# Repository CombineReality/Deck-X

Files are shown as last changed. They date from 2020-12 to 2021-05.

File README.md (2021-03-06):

# Deck X
CombineReality's open-source AR headset based on Leap Motion's Project North Star.

 

We've created a new repo because our fork had gotten a little untidy and we weren't yet ready to make pull requests.

Many of the parts in this repo are either taken directly from Leap Motion's original mechanical design. The optics brackets are derivatives of Florian Maurer's <a href="https://github.com/leapmotion/ProjectNorthStar/tree/master/Mechanical/Development">version 3.2 development work.</a>

Calibration Stand folder & files are copied from the <a href="https://github.com/leapmotion/ProjectNorthStar">Project North Star repo</a>.

Assembly guide for Deck X with threaded inserts: https://project-north-star.gitbook.io/project-north-star/mechanical/combine-reality-deck-x/deck-x-assembly-guide (Assembly guide for Deck X without threaded inserts is coming soon!) If you have any questions about how things fit together, please check the STEP files and ask for help on the Discord server. We're here for you!

The original software setup and calibration instructions for Project North Star can be found here: https://project-north-star.gitbook.io/project-north-star/

You should also consult with the community on Discord to find out about the current state of North Star software development. There's a lot going on, and documentation updates are in the works.

<br>

## Resources
* Project North Star <a href="https://discord.gg/fV8qfWm">Discord</a>
* Our <a href="https://combinereality.com">website</a>
* Deck X <a href="https://project-north-star.gitbook.io/project-north-star/mechanical/combine-reality-deck-x/deck-x-assembly-guide">Assembly Guide</a>
* <a href="https://blog.leapmotion.com/northstar/">Leap Motion Blog</a>

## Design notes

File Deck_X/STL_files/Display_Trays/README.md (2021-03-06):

There are six total variations of the display trays; three each in versions either without heat-set threaded inserts. The three versions in each of these folders each gives the headset a different optical focal depth at the center of the combiners.

The 25cm trays are best-suited for software where the bulk of the visual content will be within arm's reach. These trays produce the brightest images and the widest field of view, but more distant objects suffer from a pronounced vergence / accomodation conflict that makes them seem a bit cartoonish.

The 75cm trays are best-suited for software where most of the visual content will be beyond arm's reach, or even at a distance of many meters. This optical arrangement loses several degrees of FoV on either side, and also results in noticeably a dimmer image. But the vergence / accomodation conflict for distant objects is rendered a non-issue.

The 50cm trays are a linear interpolation between the 25cm and 75cm arrangements, and were not part of Leap Motion's initial set of options. They do, however seem to sit in a sweet spot where they fill all of the field of view for most wearers of the headset, produce an acceptably bright image (bright white content is still very close to opaque when seen in an artificially lit room), and most importantly don't result in experience-breaking vergence / accomodation conflict for content at any distance for most users.

At Combine Reality, we're currently building all of our sample and evaluation headsets with the 50cm trays without inserts, but some people still have a preference for one of the others, and this project is all about flexibility.

(See the README in ../Optics_Bracket_Assembly/Optics_Bracket_Variants_(Main_Body) for an explanation of why you might or might not want to use the heat-set inserts.)

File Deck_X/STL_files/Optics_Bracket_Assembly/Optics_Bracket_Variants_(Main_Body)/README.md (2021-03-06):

The two directories here contain two versions of the optics bracket each. You only need one of these four optics brackets for your headset build.

In one directory there are brackets that use heat-set threaded inserts that need to be installed into the brackets using a soldering iron or other appropriately heated appropriate tool. The inserts prolong the life of your headset parts if you're going to frequently remove the lid to change the arrangement of sensors, or if you plan on swapping out display trays to change the optical focal depth of the headset. In the other you will find brackets that do not require these inserts.

Each directory contains a bracket for use with the classic Leap Motion controller, and another for the Rigel sensor, now renamed the Ultraleap Stereo IR 170 Camera Module.

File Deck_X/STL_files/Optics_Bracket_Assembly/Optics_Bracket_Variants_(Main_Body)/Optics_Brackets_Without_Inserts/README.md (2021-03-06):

This version of the Deck-X Project North Star headset does away with the threaded inserts found in other versions of the headset. The rationale for this is that while the inserts do reduce wear on the parts after repeated assembly and disassembly, not all North Star builders have a soldering iron on hand. Also, counterintuitively, the inserts can make parts fit together less precisely, as builders may install the inserts themselves with differing degrees of precision.

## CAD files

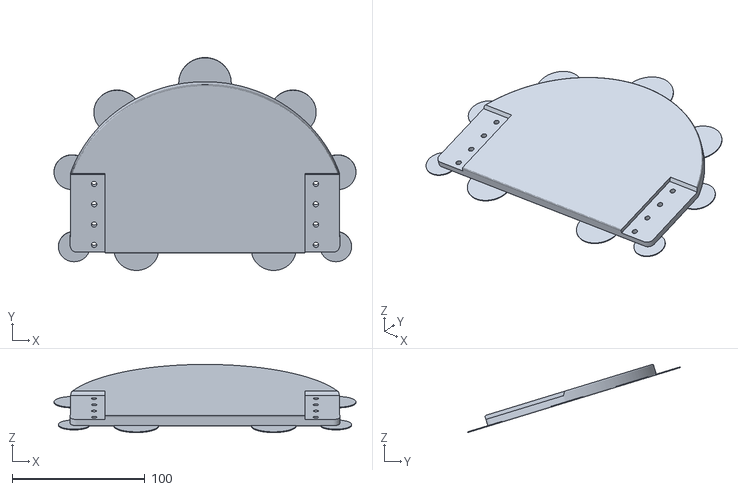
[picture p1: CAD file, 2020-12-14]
Calibration_Stand/#310-000 FDM OPTIMIZED.stl
227.5 x 160.4 x 51.4

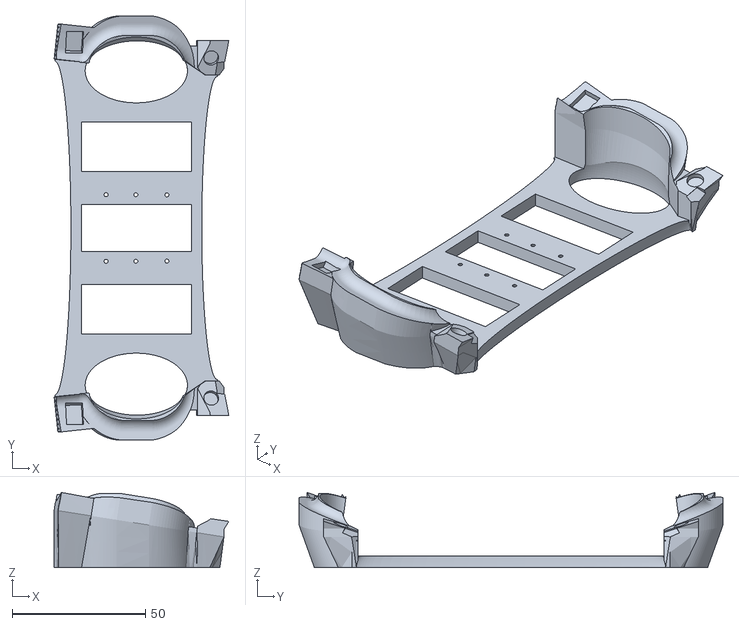
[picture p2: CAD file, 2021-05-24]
Deck_X/STL_files/Calibration_Accessories/DX_T261_Hybrid_Calibrator.stl
65.5 x 158.9 x 28.1

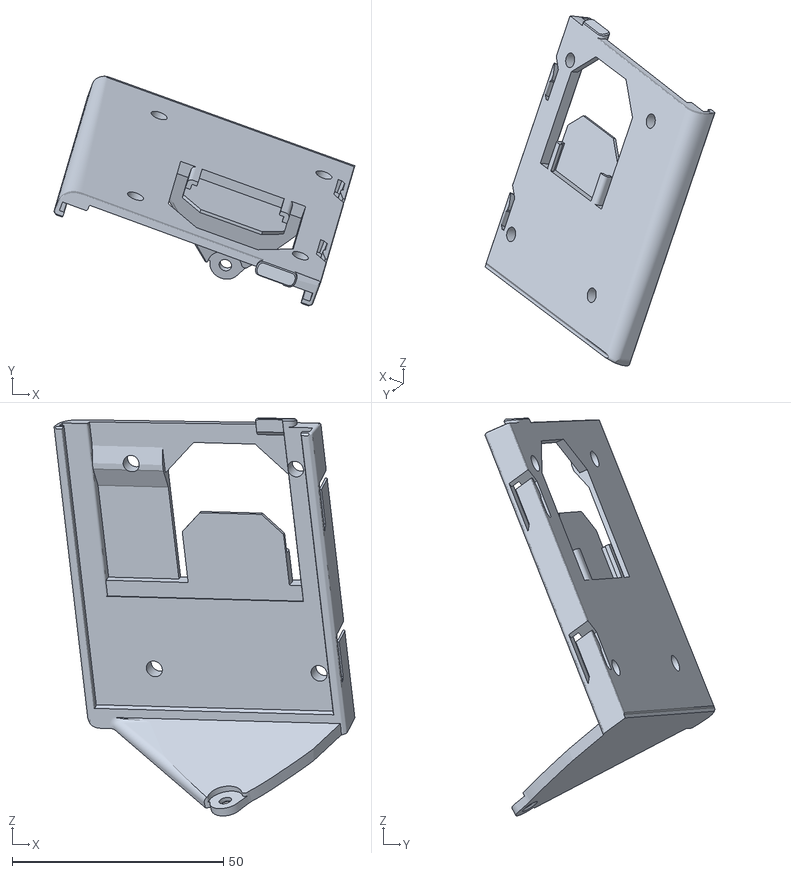
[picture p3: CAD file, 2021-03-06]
Deck_X/STL_files/Display_Trays/with_inserts/dx_tray_75_l_0105.stl
71.2 x 54.4 x 94.2

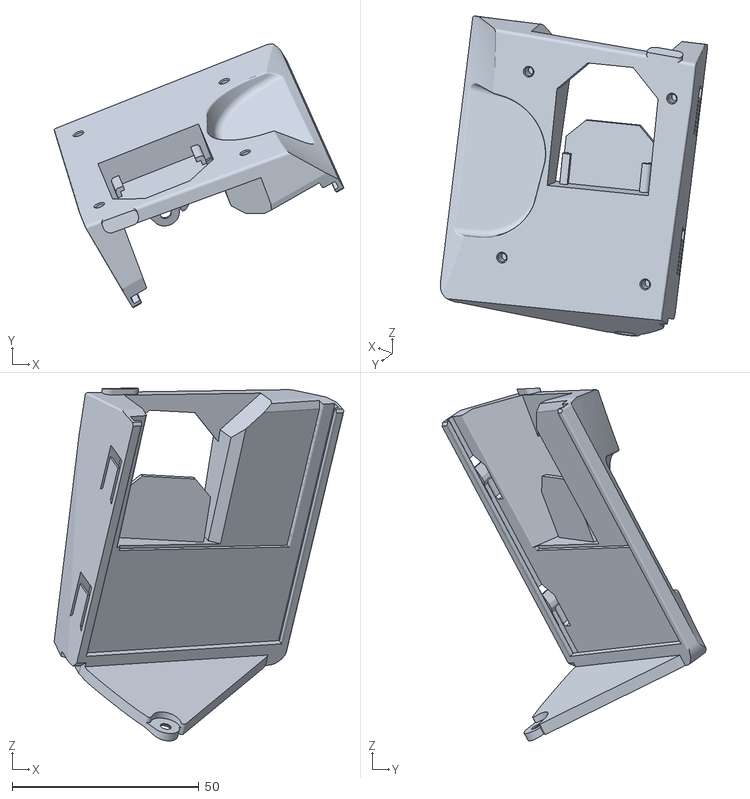
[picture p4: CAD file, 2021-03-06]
Deck_X/STL_files/Display_Trays/without_inserts/dx_tray_25_r_0105.stl
77.6 x 70.6 x 94.5

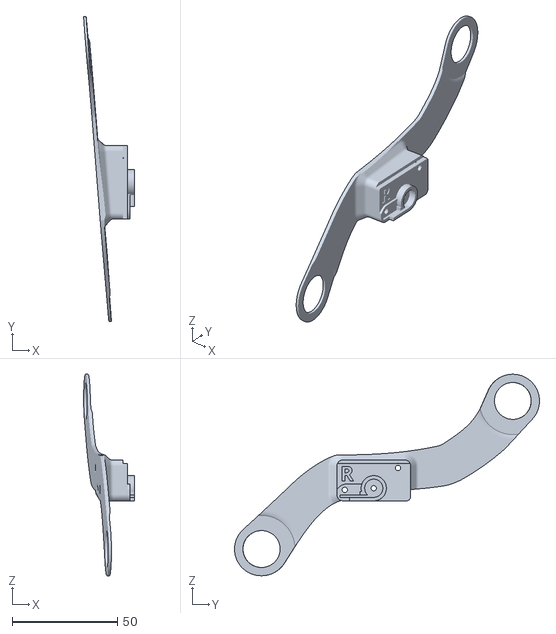
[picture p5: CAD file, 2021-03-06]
Deck_X/STL_files/Headgear/dx_headgear_strap_right.stl
24.1 x 144.8 x 95.7

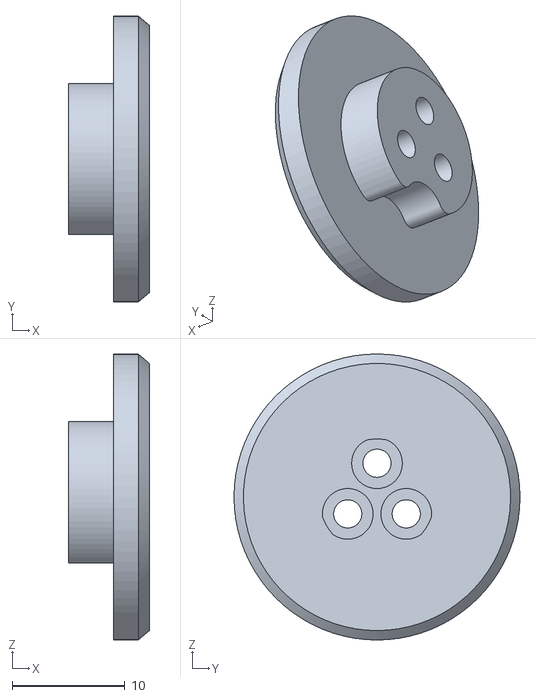
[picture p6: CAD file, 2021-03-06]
Deck_X/STL_files/Headgear/Headgear_Pivots_(Print_2x)/dx_headgear_pivot_back_male.stl
7.20 x 25.4 x 25.4

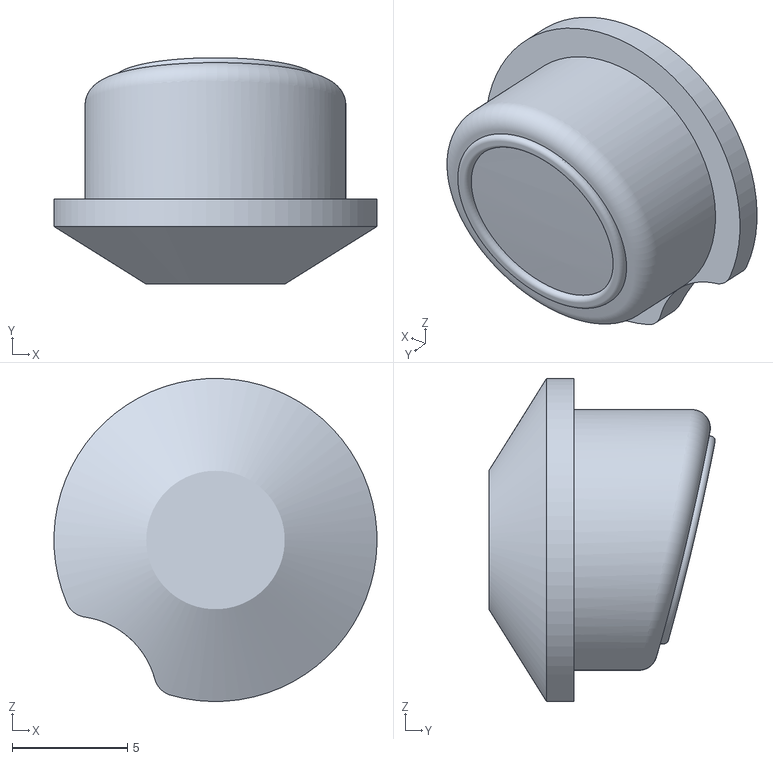
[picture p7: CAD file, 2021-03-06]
Deck_X/STL_files/Lid_Assembly/dx_button_circle_0105.stl
14.0 x 9.81 x 14.0

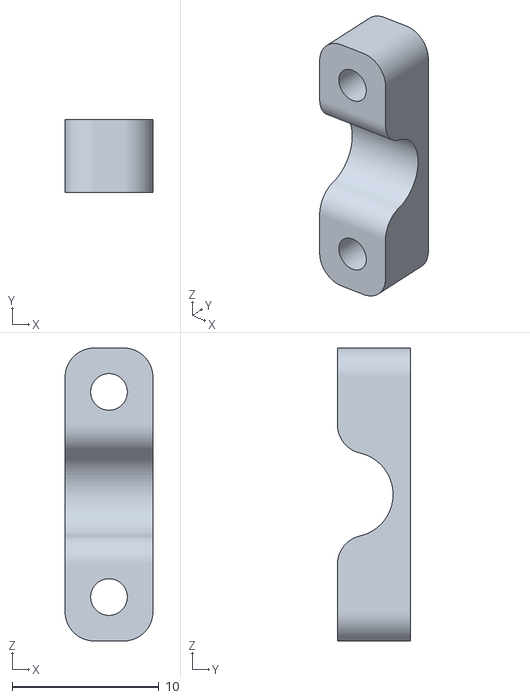
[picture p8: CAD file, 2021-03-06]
Deck_X/STL_files/Optics_Bracket_Assembly/dx_cable_restraint_r_0105.stl
6.00 x 5.00 x 20.0

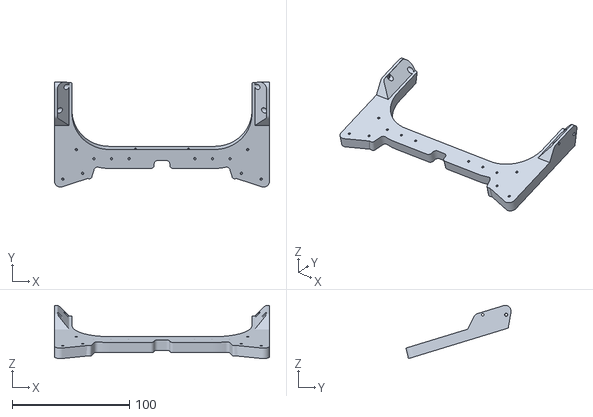
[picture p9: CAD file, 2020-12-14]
Calibration_Stand/#320-003.stl
183.1 x 89.6 x 45.3

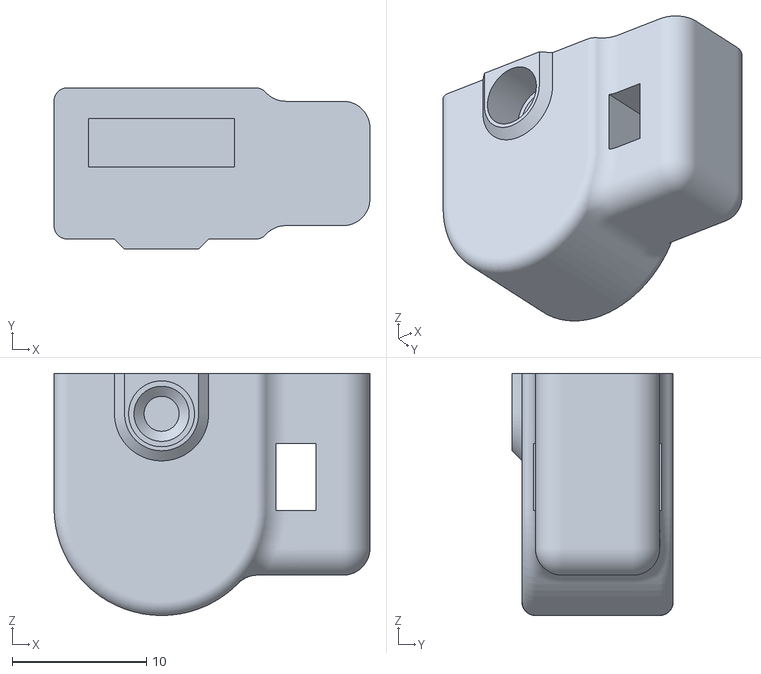
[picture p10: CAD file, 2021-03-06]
Deck_X/STL_files/Headgear/dx_slide_rail_cap_r.stl
23.5 x 12.0 x 18.0

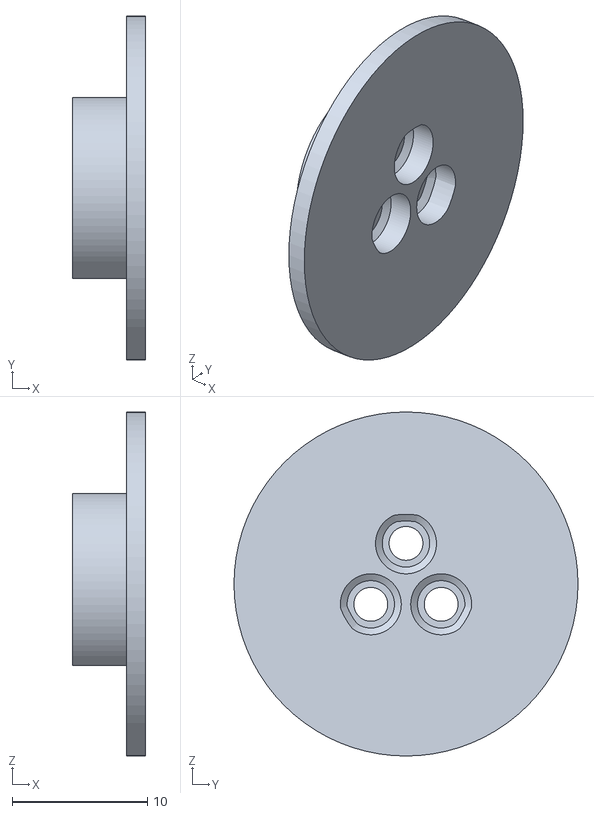
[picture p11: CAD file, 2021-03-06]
Deck_X/STL_files/Headgear/Headgear_Pivots_(Print_2x)/dx_headgear_pivot_front_male.stl
5.40 x 25.4 x 25.4

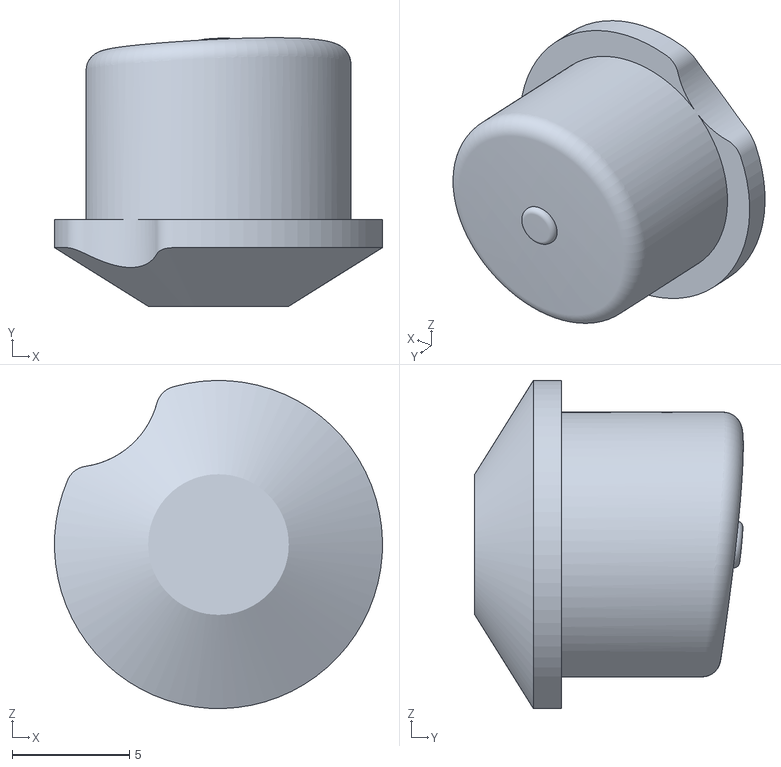
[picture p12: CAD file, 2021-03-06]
Deck_X/STL_files/Lid_Assembly/dx_button_dot_0105.stl
14.0 x 11.5 x 14.0

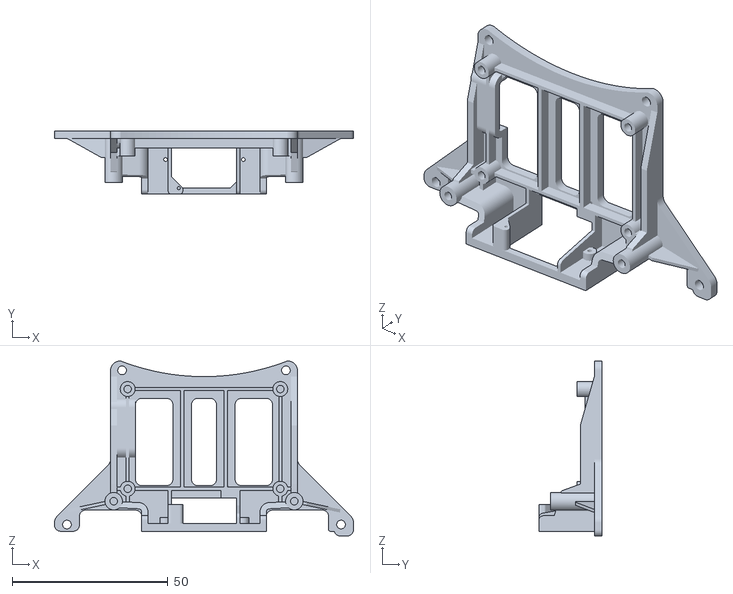
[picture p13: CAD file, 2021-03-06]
Deck_X/STL_files/Optics_Bracket_Assembly/dx_sensor_bracket_0105(CF-PETG).stl
96.0 x 20.3 x 56.2

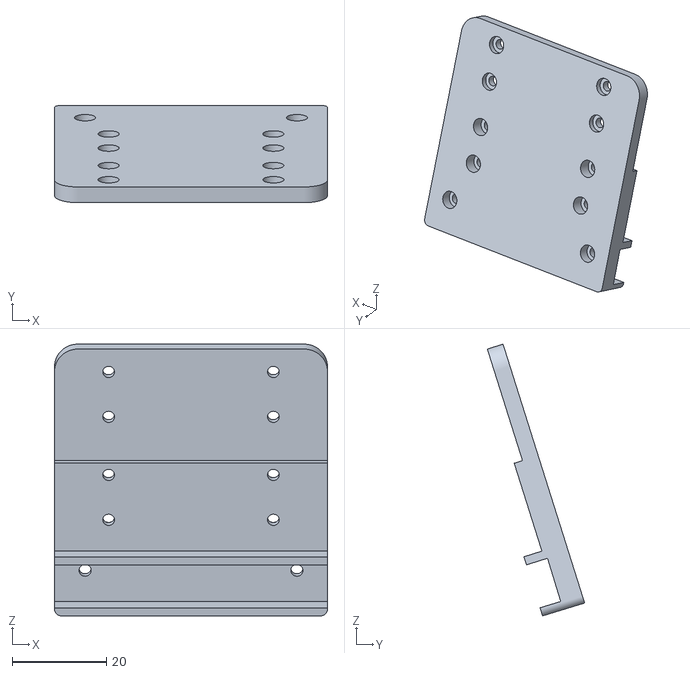
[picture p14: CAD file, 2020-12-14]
Calibration_Stand/#320-001.stl
58.0 x 20.7 x 57.7

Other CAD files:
Deck_X/STL_files/Display_Trays/with_inserts/dx_tray_25_r_0105.stl
Deck_X/STL_files/Display_Trays/without_inserts/dx_tray_25_l_0105.stl
Deck_X/STL_files/Display_Trays/with_inserts/dx_tray_50_r_0105.stl
Deck_X/STL_files/Display_Trays/without_inserts/dx_tray_75_l_0105.stl
Calibration_Stand/#310-001.stl
Calibration_Stand/#310-002 FDM OPTIMIZED.stl
Calibration_Stand/#310-002.stl
Calibration_Stand/#310-003 FDMI OPTIMIZED.stl
Calibration_Stand/#310-003.stl
Calibration_Stand/#320-002 FDMI OPTIMIZED.stl
Calibration_Stand/#320-002.stl
Calibration_Stand/#320-003 FDMI OPTIMIZED.stl
Deck_X/STL_files/Display_Trays/with_inserts/dx_tray_25_l_0105.stl
Deck_X/STL_files/Display_Trays/with_inserts/dx_tray_50_l_0105.stl
Deck_X/STL_files/Display_Trays/with_inserts/dx_tray_75_r_0105.stl
Deck_X/STL_files/Display_Trays/without_inserts/dx_tray_50_l_0105.stl
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

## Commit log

2020-12-14 Created repo & added 3D-print files
    [#210-001 - FDM OPTIMIZED.stl, #210-001.stl, #210-002.stl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]
2020-12-29 Uploaded bracket file for insert-free Deck X with Rigel module
2021-01-01 updated file names, resolved issue with display and electronics being exported as part of the 25cm and 75cm display trays
    [optics_bracket.stl, strain_relief.stl, tray_25cm_left.stl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]
2021-01-03 updated display trays and hinges so they no longer have electronics and mechanical parts attached to them
    [headgear_hinge_left.stl, headgear_hinge_right.stl, tray_25cm_left.stl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]
2021-01-03 renamed 'top case' to 'DX_Lid'
2021-01-05 Renamed files & folders
    * Renamed files in Deck_X and Deck_X_Without_Threaded_Inserts
    * Marked Deck_X folder as deprecated
    [dx_button_circle_120420.stl, dx_button_dot_120420.stl, dx_cable_restraint_120420.stl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]
2021-01-14 New design files and repo structure
    •Added up-to-date STLs for parts with heat-set inserts.
    •New versions of display trays position displays consistently over a range of different slicer settings. Hopefully will make it easier for people to have a good experience with a self-assembled heads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
    •New lid modifications address potential mechanical inference between lid and left T261 heatsink if heatsink was positioned as shown in assembly guide.
    •Small gap between lid and top of optics bracket has been addressed.
    •Minor changes to headgear part STLs.
    STEP files coming soon.
    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
    [#210-001 - FDM OPTIMIZED.stl, #210-001.stl, #210-002.stl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]
2021-03-06 Update CAD models
    Updated STEP files for Deck-X to include the combiner, added files for version with and without heat-set-inserts.
2021-05-24 Create DX_T261_Hybrid_Calibrator.stl
    Added T261 mount for calibration
    [DX_T261_Hybrid_Calibrator.stl]
